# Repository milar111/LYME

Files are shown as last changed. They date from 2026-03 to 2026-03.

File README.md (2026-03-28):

# Проект LYME: Оптичен пренос на Composite Video чрез Лазер

**Екип:** EPSON  
**Състав:** Даниел Йорданов, Радослав Славов, Виктор Христов (11 "б" клас)  



---

## Съдържание
- [1. Въведение: Целта и Еволюцията на Идеята](#1-въведение-целта-и-еволюцията-на-идеята)
  - [1.1. Основна цел на проекта](#11-основна-цел-на-проекта)
  - [1.2. Ограничения и първоначални концепции](#12-ограничения-и-първоначални-концепции)
  - [1.3. Финалното решение: Аналогово видео (Composite Video / CVBS)](#13-финалното-решение-аналогово-видео-composite-video--cvbs)
  - [1.4. Архитектура на системата (The Signal Pipeline)](#14-архитектура-на-системата-the-signal-pipeline)
- [2. Източникът на видео (The Video Source & Workarounds)](#2-източникът-на-видео-the-video-source--workarounds)
  - [2.1. Проблемът с видео източника](#21-проблемът-с-видео-източника)
  - [2.2. Първоначален Proof of Concept (ESP32)](#22-първоначален-proof-of-concept-esp32)
  - [2.3. The Workaround: Raspberry Pi като Хардуерен DAC](#23-the-workaround-raspberry-pi-като-хардуерен-dac)
  - [2.4. Софтуерна конфигурация](#24-софтуерна-конфигурация)
- [3. Предавателят (Transmitter / TX) - Анатомия на сигнала](#3-предавателят-transmitter--tx---анатомия-на-сигнала)
  - [3.1. The First Principle: Защо не свържем лазера директно към видео изхода?](#31-the-first-principle-защо-не-свържем-лазера-директно-към-видео-изхода)
  - [3.2. Етап 1: DC Biasing (Преднапрежение)](#32-етап-1-dc-biasing-преднапрежение)
  - [3.3. Етап 2: AC Coupling и "The Magic Node"](#33-етап-2-ac-coupling-и-the-magic-node)
  - [3.4. Етап 3: The Driver (Emitter Follower)](#34-етап-3-the-driver-emitter-follower)
- [4. Приемникът (Receiver / RX) - Улавяне на фотоните и възстановяване на сигнала](#4-приемникът-receiver--rx---улавяне-на-фотоните-и-възстановяване-на-сигнала)
  - [4.1. Избор на сензор: Photodiode vs. Solar Panel](#41-избор-на-сензор-photodiode-vs-solar-panel)
  - [4.2. Конфигурация на сензора: Обратно преднапрежение (Reverse Bias)](#42-конфигурация-на-сензора-обратно-преднапрежение-reverse-bias)
  - [4.3. Трансимпедансен усилвател (Transimpedance Amplifier - TIA)](#43-трансимпедансен-усилвател-transimpedance-amplifier---tia)
  - [4.4. Стабилизация и Обратна връзка (The Feedback Loop)](#44-стабилизация-и-обратна-връзка-the-feedback-loop)
- [5. Capture Phase - Войната с Импеданса (Impedance Matching)](#5-capture-phase---войната-с-импеданса-impedance-matching)
  - [5.1. Проблемът с EasyCap USB Capture Card](#51-проблемът-с-easycap-usb-capture-card)
  - [5.2. Хардуерен Hack: The 75-Ohm Series Terminator](#52-хардуерен-hack-the-75-ohm-series-terminator)
  - [5.3. Sync Slicing и Фина Калибрация](#53-sync-slicing-и-фина-калибрация)
- [6. Софтуерна Част: AI Охранителна Камера](#6-софтуерна-част-ai-охранителна-камера)
  - [6.1. Обзор на системата](#61-обзор-на-системата)
  - [6.2. Архитектура и Модули](#62-архитектура-и-модули)
  - [6.3. MediaPipe: Детекция в реално време](#63-mediapipe-детекция-в-реално-време)
  - [6.4. Qwen2.5-VL: Контекстно AI разпознаване на обекти](#64-qwen25-vl-контекстно-ai-разпознаване-на-обекти)
  - [6.5. Забранена зона и Intrusion Guard](#65-забранена-зона-и-intrusion-guard)
  - [6.6. Push известия (ntfy.sh)](#66-push-известия-ntfysh)
  - [6.7. Web UI](#67-web-ui)
  - [6.8. Главен цикъл и модел на нишките (Threading Model)](#68-главен-цикъл-и-модел-на-нишките-threading-model)
  - [6.9. Flask REST API — Пълна спецификация](#69-flask-rest-api--пълна-спецификация)
  - [6.10. HUD Рендиране (Heads-Up Display)](#610-hud-рендиране-heads-up-display)
  - [6.11. Персистентност на данните](#611-персистентност-на-данните)
  - [6.12. AI Pipeline — Вътрешен поток](#612-ai-pipeline--вътрешен-поток)
  - [6.13. Зависимости и технологичен стек](#613-зависимости-и-технологичен-стек)
- [7. Инсталация и Стартиране](#7-инсталация-и-стартиране)
  - [7.1. Локална инсталация (без Docker)](#71-локална-инсталация-без-docker)
  - [7.2. Docker контейнеризация](#72-docker-контейнеризация)
  - [7.3. Конфигурация](#73-конфигурация)
  - [7.4. Тестване на Docker контейнеризацията](#74-тестване-на-docker-контейнеризацията)

---

## 1. Въведение: Целта и Еволюцията на Идеята 

### 1.1. Основна цел на проекта
Основната цел на проект LYME е изграждането на изцяло custom хардуерен оптичен линк (по въздуха, чрез лазерен лъч), способен да предава видео сигнал в реално време. 

Идеята е да се създаде стабилна система за оптична комуникация в свободно пространство (Free Space Optics), която доказва, че базов аналогов хардуер може да поддържа висока честотна лента (Bandwidth). Възможността този възстановен видео сигнал впоследствие да се подаде към лаптоп за анализ от AI модел за компютърно зрение е просто допълнително приложение (use-case). 

### 1.2. Ограничения и първоначални концепции
За да докажем концепцията (Proof of Concept) по възможно най-категоричния начин, умишлено търсихме най-трудното за реализация решение. Тривиалните методи за пренос на данни бяха изключени на ранен етап:
* **Пренос на текст (UART през оптика):** Изисква много ниска честотна лента (baud rates от порядъка на 9600 до 115200 bps). Това прави хардуерната реализация елементарна, но не демонстрира капацитета на линка.
* **Пренос на аудио:** Аудио сигналите са ограничени в тесен честотен диапазон (20Hz - 40kHz). Модулацията на лазер с аудио е възможна с базови компоненти, но отново не натоварва системата достатъчно.

Решихме да предаваме видео, защото то поставя хардуера на абсолютния му лимит. В процеса на проектиране преминахме през два неуспешни теоретични модела:

#### Провалена идея 1: Дигитално видео (Digital Baseband Transmission)
Логичният първи подход беше предаване на сурови дигитални данни (нули и единици). Проблемът тук е лимитацията на физическия слой (Physical Layer) и чистата математика на дигиталното видео:
* За да се предаде некомпресирано изображение с базова резолюция от 640x480 пиксела в 8-bit grayscale (черно-бяло), обемът данни за един единствен кадър е `640 * 480 * 1 byte = 307,200 bytes` (около 2.45 Megabits).
* Ако нашият DIY линк (базов микроконтролер и транзистор) успее да постигне скорост на превключване от 1 Mbps (което е силно оптимистично без специализирани оптични трансивъри), системата ще предава **под 0.5 кадъра в секунда (FPS)**.
* Ако целим гладко видео с минимум 15 FPS, математиката ни принуждава да намалим резолюцията до приблизително 32x32 пиксела – резолюция, която визуално не доказва нищо и е неизползваема за каквито и да е практически цели.

#### Провалена идея 2: Снимки чрез звук
Следващият подход беше конвертирането на статични изображения в аудио тонове, които лазерът да предава. 
* **Предимство:** Изключително надежден метод при наличие на интерференции, тъй като аудио честотите са лесни за филтриране.
* **Недостатък:** Кодирането и предаването на една статична снимка с приемливо качество отнема между 8 и 120 секунди. Това въвежда огромно времезакъснение (latency) и премахва елемента на "реално време".



### 1.3. Финалното решение: Аналогово видео (Composite Video / CVBS)
Решението на проблема с честотната лента се оказа връщането към аналоговите стандарти. Composite Video (CVBS) предоставя перфектния баланс между качество, скорост и хардуерна приложимост:
* Един единствен аналогов сигнал (вълна) с честотна лента от около **5 MHz** побира в себе си цялата необходима информация: синхронизиращи импулси (H-Sync/V-Sync), информация за яркостта (Luma) и цвета (Chroma).
* Вместо да се превключват милиони отделни битове (On/Off), лазерът се модулира амплитудно – неговият интензитет (яркост) следва точно напрежението на аналоговата вълна.
* Този метод заобикаля дигиталните ограничения за честотна лента и позволява постигането на плавни **50/60 кадъра в секунда (FPS)** при запазване на висока визуална разделителна способност.



### 1.4. Архитектура на системата (The Signal Pipeline)
За реализирането на тази концепция беше изграден следният комуникационен канал:

1.  **Източник:** Камера, чийто дигитален сигнал се чете от Raspberry Pi.
2.  **DAC Конвертиране:** Raspberry Pi използва хардуерния си TV-out, за да енкодира сигнала в аналогов Composite Video формат.
3.  **Transmitter (TX Circuit):** Предавателна схема, която наслагва AC видео сигнала върху DC bias и управлява мощността на лазерния диод.
4.  **Преносна среда:** Лазерен лъч в свободно пространство.
5.  **Сензор:** BPW34 фотодиод, работещ в Reverse Bias за максимална скорост.
6.  **Receiver (RX Circuit):** Transimpedance Amplifier (TIA), който конвертира микроскопичния фототок обратно във видео напрежение (Volts).
7.  **Дигитализиране:** USB Capture Card, която подава възстановения сигнал към лаптоп за визуализация и евентуален AI анализ.



## 2. Източникът на видео (The Video Source & Workarounds)

### 2.1. Проблемът с видео източника
Оптималният източник за тестване на аналогов линк е native аналогова охранителна камера (CCTV). Поради липса на такъв хардуер, се наложи да изградим система, която да генерира и излъчва валиден Composite Video (CVBS) сигнал, използвайки наличната дигитална техника.

### 2.2. Първоначален Proof of Concept (ESP32)
Преди да започнем пренос на живо видео, трябваше да изолираме променливите и да докажем, че самият аналогов лазерен линк работи. За целта използвахме **ESP32 микроконтролер**. 
* **Защо ESP32?** ESP32 разполага с хардуерни 8-битови цифрово-аналогови преобразуватели (DAC). 
* Чрез специализиран код, ESP32 генерира перфектни NTSC статични тестови екрани (Test Patterns), извеждайки аналоговата вълна директно през **Pin 26**. 
* Това позволи калибрирането на предавателя и приемника в контролирана среда, преди да въведем сложността на "живата" камера и операционната система на Raspberry Pi.

  

### 2.3. The Workaround: Raspberry Pi като Хардуерен DAC
За преноса на видео в реално време използвахме **Raspberry Pi**, свързано с дигитална камера. Raspberry Pi действа като мост и дигитално-аналогов преобразувател:
1.  Чете дигиталния видео стрийм от камерата.
2.  Използва вградения си хардуерен видео енкодер (Hardware TV-out), за да модулира дигиталните пиксели в стандартизиран аналогов PAL/NTSC CVBS сигнал.
3.  Извежда сигнала през аналоговия (жълт) RCA порт.

### 2.4. Софтуерна конфигурация
* **Операционна система (Debian Buster):** За проекта използвахме по-старата версия на Raspberry Pi OS (Buster/Legacy). Причината е чисто архитектурна: по-новите версии (Bullseye/Bookworm) използват различен графичен стек (Wayland/Mutter), който често създава конфликти при опит за директен достъп до хардуерния композитен изход. Старият стек е доказано по-стабилен за генериране на чист аналогов сигнал.
* **Headless управление (SSH):** Цялото управление се извършва безжично през SSH (`ssh pi@raspberrypi.local`). Това е критично, защото свързването на HDMI монитор за управление би изключило автоматично аналоговия композитен порт.
* **Екзекуция на потока:** Видеото се стартира чрез директна команда към видео ядрото: `sudo ffmpeg -f v4l2 -video_size 640x480 -i /dev/video0 -pix_fmt rgb565le -f fbdev /dev/fb0`

---

## 3. Предавателят (Transmitter / TX) - Анатомия на сигнала

### 3.1. The First Principle: Защо не свържем лазера директно към видео изхода?
Видео изходът на Raspberry Pi (и на повечето устройства) е стандартизиран AC (променливотоков) сигнал с амплитуда около **1.0V (peak-to-peak)**. 
От друга страна, стандартен червен лазерен диод изисква:
1.  **Постоянно напрежение (DC Bias):** Минимум 2.5V - 3.0V само за да преодолее вътрешната си бариера (Forward Voltage - $V_f$) и да започне да свети.
2.  **Ток (Current):** Около 20mA до 30mA за стабилна работа, което надвишава безопасния лимит на видео изходите.
Ако свържем лазера директно, той никога няма да светне, защото напрежението от 1V е недостатъчно. Необходимо е да изградим активна схема за смесване и усилване.

### 3.2. Етап 1: DC Biasing (Преднапрежение)
За да може лазерът да предава промените във видеото (светло/тъмно), той трябва първоначално да свети със средна интензивност. Това е "носещата" светлина.
* Използваме **10k потенциометър** свързан между +5V и GND като делител на напрежение.
* Средният пин на потенциометъра подава постоянно DC напрежение (настроено чрез въртене) през предпазен **1k резистор** към базата на транзистора. Това поддържа лазера постоянно включен в оптималната му работна точка (Q-point).

### 3.3. Етап 2: AC Coupling и "The Magic Node"
Трябва да добавим променливия видео сигнал (AC) върху постоянното захранване (DC), без двете вериги да окъсят една друга.
* Видео сигналът преминава през комбинация от паралелно свързани кондензатори: **47µF електролитен** и **100nF керамичен**.
* **Защо два кондензатора?** Електролитният кондензатор (47µF) пропуска перфектно ниските честоти (като 50Hz V-Sync импулси), но има висока паразитна индуктивност (ESL) и блокира високите честоти. Керамичният (100nF) реагира мигновено на високите честоти (MHz детайлите на картината). Работейки заедно, те покриват целия спектър на Composite Video сигнала.
* Кондензаторите блокират DC тока, но пропускат AC вълната. Точно след тях, видео вълната се наслагва върху DC напрежението от потенциометъра. Този възел ("Magic Node") съдържа перфектно миксирания сигнал, готов за усилване.

### 3.4. Етап 3: The Driver (Emitter Follower)
Слабият смесен сигнал (от порядъка на микроампери) влиза в Базата (Base) на **2N2222 NPN транзистор**.
* Транзисторът е свързан в конфигурация **Общ Колектор (Common Collector)**, известна още като **Emitter Follower**.
* **Защо тази конфигурация?** При нея транзисторът не усилва напрежението (напрежението на Емитера просто следва това на Базата, минус ~0.7V вътрешен пад), но усилва драстично **тока**. Транзисторът взема нужния голям ток директно от +5V захранването (Колектора) и го подава към лазера (Емитера), следвайки перфектно формата на видео вълната, без да натоварва Raspberry Pi-то.




## 4. Приемникът (Receiver / RX) - Улавяне на фотоните и възстановяване на сигнала

След като видео сигналът е пренесен през свободното пространство под формата на модулирана светлина, приемната страна трябва да извърши обратния процес: преобразуване на вариациите в светлинния интензитет обратно в електрическо напрежение с честотна лента от ~5 MHz.

### 4.1. Избор на сензор: Photodiode vs. Solar Panel
Често срещана грешка в любителските оптични линкове е използването на малки соларни панели като приемници. За пренос на видео този подход е физически невъзможен поради архитектурата на компонентите:
* **Соларните панели** са проектирани за енергиен добив. Те имат огромна площ на PN прехода, което води до екстремно висок вътрешен паразитен капацитет (често в порядъка на микрофаради). Този капацитет действа като нискочестотен филтър (Low-Pass Filter), ограничавайки скоростта на реакция до десетки херца.
* **PIN Фотодиодът (BPW34)**, избран за този проект, е проектиран специфично за високоскоростно предаване на данни. Той има малък капацитет и изключително бързо време за реакция (Rise/Fall time).

### 4.2. Конфигурация на сензора: Обратно преднапрежение (Reverse Bias)
Дори и бърз фотодиод като BPW34 не би се справил с 5 MHz видео сигнал, ако бъде свързан във фотоволтаичен режим (генерация на ток без външно напрежение). 
* За да постигнем необходимата скорост, BPW34 е свързан в режим на **Обратно преднапрежение (Reverse Bias)**. Анодът е свързан към отрицателната захранваща линия (**-9V**), а катодът към виртуалната нула на усилвателя.

### 4.3. Трансимпедансен усилвател (Transimpedance Amplifier - TIA)
Фотодиодът генерира ток, който е правопропорционален на падащата светлина (фототок), но този ток е микроскопичен (в порядъка на наноампери до микроампери). Стандартните видео входове изискват напрежение (обикновено около 1Vpp). За преобразуването се използва **Transimpedance Amplifier (TIA)**.

* **Избор на Операционен Усилвател (Op-Amp):** Използван е високоскоростният операционен усилвател **LM318N**. Стандартни аудио усилватели (като LM358 или TL072) са напълно неподходящи, тъй като техният Gain-Bandwidth Product (GBWP) и Slew Rate (скорост на нарастване на напрежението) са твърде ниски и биха "смачкали" видео сигнала. LM318N предлага 15 MHz честотна лента, което е повече от достатъчно за запазване на острите ръбове на синхронизиращите импулси.
* **Двойно захранване (Dual Power Supply):** Схемата се захранва с две 9V батерии, формиращи истинско двойно захранване (**+9V, GND, -9V**). Това е критично, за да може AC видео сигналът на изхода да осцилира свободно и симетрично около нулата, без да се получи изрязване (clipping) на амплитудата.

### 4.4. Стабилизация и Обратна връзка (The Feedback Loop)
Поведението на TIA се определя от компонентите в неговата обратна връзка (между изхода Pin 6 и инвертиращия вход Pin 2):
1.  **Съпротивление за усилване ($R_f = 2.2k\Omega$):** Определя коефициента на преобразуване ток-напрежение ($V_{out} = -I_{photo} \times R_f$). Стойността от 2.2k е избрана като компромис между достатъчно силен изходен сигнал и запазване на висока честотна лента.
2.  **Компенсиращ кондензатор ($C_f = 8.2pF$):** Това е най-критичният пасивен елемент в приемника. Входният капацитет на Op-Amp-а и капацитетът на фотодиода създават полюс в предавателната функция, който причинява дестабилизация и високочестотни осцилации (звънене/ringing). Паралелният кондензатор от 8.2pF е прецизно подбран (въз основа на капацитета на прехода на BPW34 при -9V), за да въведе нула в предавателната функция, която компенсира полюса. Това стабилизира усилвателя (Phase Margin > 45°) и изчиства видео сигнала.




## 5. Capture Phase - Войната с Импеданса (Impedance Matching)

След успешното възстановяване на сигнала от трансимпедансния усилвател, той трябва да бъде подаден към дигитализиращо устройство. По време на тестовете се сблъскахме със сериозен проблем на физическо ниво при прехода от аналогов към цифров формат.

### 5.1. Проблемът с EasyCap USB Capture Card
При първоначалните тестове, изходът от приемника беше подаден директно към съвременен телевизор с native RCA вход. Картината беше стабилна и ясна. Когато същият сигнал беше подаден към евтина USB Capture карта (EasyCap), изображението страдаше от тежко хоризонтално размазване (smearing/ghosting) и диагонално накъсване (Horizontal Sync Loss).

* **Причината:** Телевизорите разполагат с висококачествени схеми за автоматичен контрол на усилването (Auto Gain Control - AGC) и толерантни филтри. EasyCap устройствата използват базови и изключително стриктни "Sync Slicer" интегрирани схеми. Те очакват перфектно съгласуван сигнал с точна амплитуда от ~1.0V (peak-to-peak) и перфектни черни нива за синхронизиращите импулси.

### 5.2. Хардуерен Hack: The 75-Ohm Series Terminator
Най-критичната модификация в приемната част беше добавянето на съгласуващ резистор.
* **Физиката на проблема:** Операционният усилвател (LM318N) има много нисък изходен импеданс (близък до 0 ома) и "блъска" видео сигнала в RCA кабела с голяма мощност. Когато този сигнал стигне до Capture картата, част от енергията преминава, но друга част се отразява обратно по кабела поради несъответствие във съпротивление. Тези отражения (електрическо ехо) се наслагват върху оригиналния сигнал и причиняват визуалното хоризонтално размазване.
* **Решението:** Добавяне на **75-омов резистор последователно (в серия)** на изхода, веднага след 100µF AC Coupling кондензатора и преди централния пин на RCA жака.
* **Резултатът:** Този резистор осъществява съгласуване на импеданса на източника (Source Impedance Matching). Той абсорбира отразените от Capture картата вълни, спира "ехото" и възстановява острите вертикални ръбове на текста и обектите в картината.

### 5.3. Sync Slicing и Фина Калибрация
Диагоналното накъсване на картината се дължеше на прекалено високо напрежение на възстановения сигнал, което "заслепяваше" Sync Slicer-а на Capture картата. 
* За да може EasyCap да "заключи" картината, той трябва да разпознае H-Sync импулсите като най-ниското ниво на напрежение в целия сигнал.
* **Процесът на калибрация:** Чрез микроскопично въртене на 10k потенциометъра на **предавателя (TX)**, ние ръчно намалявахме базовия DC Bias на лазера. Това физически понижи общата амплитуда на възстановения сигнал на приемника, докато той не влезе в стриктния "прозорец" на EasyCap чипа. В този момент диагоналното разкъсване изчезна и се установи стабилен 50/60 FPS видео поток.

---

## 6. Софтуерна Част: AI Охранителна Камера

### 6.1. Обзор на системата
Софтуерната част на LYME представлява AI-базирана охранителна система, която обработва видео потока, получен от лазерния оптичен линк. Системата работи в реално време и изпълнява следните функции:

* **Детекция на хора** — чрез MediaPipe Pose Landmarker, системата разпознава човешки фигури с ниска латентност.
* **Разпознаване на обекти** — MediaPipe EfficientDet идентифицира познати обекти (чаши, бутилки, чадъри и др.) в кадъра.
* **Разпознаване на жестове** — MediaPipe Gesture Recognizer следи ръцете и разпознава жестове в реално време.
* **Контекстно AI разпознаване** — Qwen2.5-VL визуален езиков модел (VLM) анализира зоната на интерес и отговаря на въпроси от вида "Има ли бутилка в кадъра?", връщайки резултат с процент увереност.
* **Забранена зона** — потребителят дефинира полигонална зона през уеб интерфейса; навлизането на човек предизвиква аларма.
* **Push известия** — при засечени нарушения или обекти, системата автоматично изпраща push нотификации през ntfy.sh към телефон/компютър.

### 6.2. Архитектура и Модули

```
main.py                     ← Входна точка: стартира камера, AI, Flask сървър
├── src/
│   ├── tracker.py           ← VisionTracker: обвива 3-те MediaPipe модела
│   ├── actions.py           ← Зарежда Qwen2.5-VL и изпълнява AI заявки
│   ├── context_manager.py   ← Списък с наблюдавани обекти + генерира промпти
│   ├── zone_manager.py      ← Логика за забранена зона (полигон)
│   ├── intrusion_guard.py   ← State machine: CLEAR → DWELLING → INTRUDING
│   ├── alerts.py            ← Логване на събития + запис на snapshot-и
│   ├── notifier.py          ← Push известия чрез ntfy.sh
│   └── config.py            ← Централна конфигурация
├── demo_app/
│   └── templates/
│       └── index.html       ← Web UI (единичен HTML файл)
├── Dockerfile               ← Docker image дефиниция
├── docker-compose.yml       ← Оркестрация
└── requirements.txt         ← Python зависимости
```

### 6.3. MediaPipe: Детекция в реално време
Модулът `VisionTracker` (`src/tracker.py`) инициализира три MediaPipe модела, които работят паралелно в **LIVE_STREAM** режим:

| Модел | Файл | Функция |
|---|---|---|
| Pose Landmarker Full | `pose_landmarker_full.task` | Детекция на 33 точки от тялото на човек |
| EfficientDet Lite0 | `efficientdet_lite0.tflite` | Обща детекция на обекти (COCO dataset) |
| Gesture Recognizer | `gesture_recognizer.task` | Разпознаване на жестове на ръце |

Моделите се изтеглят автоматично от Google Storage при първо стартиране. Резултатите от всеки модел се записват чрез callback функции, което позволява неблокиращо (асинхронно) обработване на кадри.

**Pose Landmarker** е ключов за функцията "Забранена зона" — центърът на тялото (средна точка между лявото и дясното рамо) се изчислява и проверява дали попада в дефинирания полигон.

### 6.4. Qwen2.5-VL: Контекстно AI разпознаване на обекти
За задачи, които MediaPipe не може да покрие (например "Има ли бутилка вода в зоната?"), системата използва **Qwen2.5-VL-3B-Instruct** — 3-милиарден параметър визуален езиков модел (VLM), работещ изцяло локално на CPU.

**Как работи:**
1. Потребителят добавя обект за наблюдение (напр. "bottle") през уеб интерфейса.
2. Системата генерира детайлен промпт: *"Look very carefully at this image. Is there a 'bottle' (or any similar/related object) visible anywhere in the frame, even partially, at an angle, in shadow, or partially outside the frame?..."*
3. На всеки 5 секунди (`_AI_INTERVAL`), Qwen получава текущия кадър (изрязан до забранената зона) и един от промптите. Обработката се случва в отделна нишка, за да не блокира видео потока.
4. Моделът отговаря в строго дефиниран формат: `CONFIDENCE: 85% | yes | A water bottle is visible on the table`
5. Отговорът се парсва за **процент увереност** и **да/не** решение.

**Система за потвърждение (Dwell):** За да се избегнат фалшиви аларми, обектът трябва да бъде засечен **поне 2 пъти последователно** (в рамките на `_ITEM_DWELL_SECONDS = 2.0s`), преди да се изпрати push известие. При всяко сканиране, процентът увереност се визуализира в реално време както в уеб интерфейса, така и директно върху видео потока.

### 6.5. Забранена зона и Intrusion Guard
Системата за забранена зона се състои от два комплементарни модула:

**Zone Manager** (`src/zone_manager.py`):
* Зоната е полигон, дефиниран с нормализирани координати (0.0–1.0) и съхранен в `data/zone.json`.
* Потребителят рисува полигона директно върху видео потока чрез уеб интерфейса — кликване добавя точка, десен клик премахва последната, бутон "Confirm" записва зоната.
* Функцията `body_centre_in_zone()` използва `cv2.pointPolygonTest()` за проверка дали центърът на тялото попада вътре в полигона.

**Intrusion Guard** (`src/intrusion_guard.py`):
* Реализира State Machine с три състояния:
  - **CLEAR** — Няма човек в зоната.
  - **DWELLING** — Човек е засечен, но тече период на изчакване (`INTRUSION_DWELL_SECONDS = 2.0s`), визуализиран с progress bar на екрана.
  - **INTRUDING** — Потвърдено нарушение. Активира се аларма, записва се snapshot, изпраща се push известие.
* Този подход с "dwell time" елиминира фалшиви аларми от моментно преминаване или грешки в детекцията.

### 6.6. Push известия (ntfy.sh)
Модулът `src/notifier.py` изпраща push известия чрез безплатния и open-source сервис **ntfy.sh**. Не се изисква регистрация — достатъчно е да се абонирате за topic-а (конфигуриран в `src/config.py` → `NTFY_TOPIC`).

**Типове известия:**
| Събитие | Приоритет | Описание |
|---|---|---|
| 🚨 INTRUSION DETECTED | urgent | Човек навлязъл в забранената зона |
| ✅ Zone cleared | default | Зоната е отново празна |
| 🔍 OBJECT DETECTED | urgent | AI моделът е засякъл наблюдаван обект |

Всяко известие включва AI описание и процент увереност. Intrusion alert-ите съдържат допълнителен контекст за всички текущо наблюдавани обекти.

### 6.7. Web UI
Интерфейсът (`demo_app/templates/index.html`) е единичен HTML файл, сервиран от Flask на порт **4000**. Той предоставя:

* **Видео стрийм** — MJPEG поток (`/video_feed`) с наложени HUD елементи (confidence overlay, intrusion banner, dwell progress bar).
* **Панел "System Status"** — Текущо състояние: CLEAR / DWELLING / INTRUDING.
* **Панел "Forbidden Zone"** — Рисуване, потвърждаване и изчистване на полигонална зона.
* **Панел "Monitor For"** — Добавяне/премахване на обекти за AI наблюдение (напр. bottle, knife, bag).
* **Панел "AI Detections"** — За всеки обект: статус иконка (⏳/⚠️/✅), процент увереност с цветен индикатор, кратко описание от AI модела, progress bar с увереност.
* **Event Log** — Хронологичен лог на всички събития.
* **Бутон "Shutdown"** — Спира системата.

### 6.8. Главен цикъл и модел на нишките (Threading Model)
Системата използва многонишков (multi-threaded) модел, за да осигури едновременна работа на видео обработката и уеб сървъра:

**Стартова последователност:**
1. `actions.init_model()` — зарежда Qwen2.5-VL модела в паметта (~6 GB RAM на CPU).
2. `VisionTracker()` — инициализира трите MediaPipe модела; при първо стартиране ги изтегля автоматично от Google Storage.
3. `cv2.VideoCapture()` — отваря камерата (индексът се конфигурира от `config.CAMERA_SOURCE`).
4. `init_zone()` / `init_context()` — зареждат запазената забранена зона и списъка с наблюдавани обекти от `data/`.
5. Flask сървърът се стартира в **daemon нишка** (`threading.Thread(target=run_flask, daemon=True)`).

**Нишки в системата:**

| Нишка | Описание |
|---|---|
| **Main Thread** | Главният цикъл `while _running` — чете кадри от камерата, обработва ги чрез MediaPipe, проверява зоната, рисува HUD-а и обновява `WebUIState`. |
| **Flask Thread** | Daemon нишка — сервира уеб интерфейса на порт 4000 и обслужва REST API заявки. |
| **Qwen AI Thread** | Порожда се при нужда (на всеки `_AI_INTERVAL = 5s`) — изпълнява `_run_qwen_async()` в отделна daemon нишка. Използва `_ai_busy` флаг за да предотврати припокриване. |
| **Notifier Thread** | Порожда се при всяко push известие — изпраща HTTP POST към ntfy.sh асинхронно. |
| **Alert Thread** | Порожда се при всяка аларма — записва snapshot и логва събитието без да блокира видео потока. |

**Синхронизация:** Споделеното състояние (`WebUIState`, `_answers`, `_questions`, `_items`) е защитено с `threading.Lock` обекти. Флагът `_ai_busy` предотвратява стартирането на втора Qwen заявка, докато предишната не е завършила.

**Грациозно спиране:** Натискането на `Ctrl+C` или извикването на `POST /shutdown` задава `_running = False`, което прекъсва главния цикъл. Блокът `finally` освобождава камерата и затваря MediaPipe моделите.

### 6.9. Flask REST API — Пълна спецификация
Flask сървърът е достъпен на `http://localhost:4000` и предоставя следните ендпойнти:

| Метод | Ендпойнт | Описание |
|---|---|---|
| `GET` | `/` | Сервира `index.html` — уеб интерфейса |
| `GET` | `/video_feed` | MJPEG стрийм — непрекъснат поток от JPEG кадри с наложен HUD |
| `GET` | `/status` | JSON: `person_in_sight`, `is_intruding`, `guard_state`, `dwell_progress`, `last_seen_ago`, `frame_count`, `object_alert` |
| `GET` | `/ai_status` | JSON масив с елементи за всеки наблюдаван обект: `item`, `answer`, `description`, `confidence`, `detected` |
| `GET` | `/zone` | JSON: текущите нормализирани точки на полигона (или `null`) |
| `POST` | `/zone` | Приема JSON `{"points": [{x, y}, ...]}` — записва зоната и я зарежда без рестарт |
| `DELETE` | `/zone` | Изтрива забранената зона от паметта и от `data/zone.json` |
| `GET` | `/context` | JSON масив с имена на наблюдавани обекти |
| `POST` | `/context` | Приема JSON `{"item": "bottle"}` — добавя нов обект за AI наблюдение |
| `DELETE` | `/context/<idx>` | Премахва обект по индекс от списъка |
| `POST` | `/shutdown` | Спира системата — задава `_running = False` |
| `GET` | `/debug/ai_crop` | Debug ендпойнт — показва изрязания кадър, който Qwen вижда |

**MJPEG потокът** (`/video_feed`) е реализиран чрез `multipart/x-mixed-replace` MIME тип. Браузърът получава непрекъснат поток от JPEG изображения, разделени с boundary маркери — не е необходим WebSocket или допълнителен JavaScript за видео визуализация.

### 6.10. HUD Рендиране (Heads-Up Display)
Всеки кадър от видео потока се обогатява с визуални елементи преди кодирането му в JPEG:

* **Зони** (`draw_zones()`): Забранената зона се рисува като полупрозрачен червен полигон (`cv2.fillPoly` + `cv2.addWeighted` с alpha = 0.25). При активна аларма, прозрачността се увеличава до 0.45 и контурът се удебелява. Текстът "FORBIDDEN ZONE" се позиционира в центъра на полигона, а "FREE ZONE" — в средната точка на свободната област.

* **AI Confidence Overlay** (`_draw_ai_confidence_hud()`): В горния ляв ъгъл се рендира полупрозрачен панел с информация за всеки наблюдаван обект:
  - `[?]` сиво — AI все още не е сканирал
  - `[OK]` зелено — обектът не е засечен (confidence < 40%)
  - `[~]` оранжево — несигурен резултат (40-59%)
  - `[!]` червено — обектът е засечен (confidence ≥ 60%)

* **Dwell Progress Bar**: Когато човек е в зоната и системата е в състояние `DWELLING`, в долната част на кадъра се рисува оранжева лента, запълваща се от 0% до 100% за `INTRUSION_DWELL_SECONDS` секунди.

* **Intrusion Banner**: При потвърдено нарушение (`INTRUDING`), в долната част се изписва мигащ червен банер "!! INTRUSION DETECTED !!" върху полупрозрачен черен фон. Рамката на целия кадър става червена.

### 6.11. Персистентност на данните
Системата съхранява данни в директория `data/`, която се създава автоматично при първо стартиране:

| Файл / Директория | Описание |
|---|---|
| `data/zone.json` | Нормализирани координати на забранената зона `[[x, y], ...]` |
| `data/context.json` | JSON масив с имена на наблюдавани обекти `["bottle", "knife"]` |
| `data/logs.txt` | Текстов лог с времеви печат за всяко събитие (intrusion, object detection) |
| `data/snapshots/` | JPEG изображения, записвани автоматично при аларма (`intrusion_YYYYMMDD_HHMMSS.jpg`) |
| `data/.model_initialized` | Флагов файл, указващ че моделите са инициализирани |

При Docker контейнеризация, `data/` директорията се монтира като volume (`./data:/app/data`), така че данните преживяват рестартиране на контейнера.

### 6.12. AI Pipeline — Вътрешен поток
AI обработката следва строго определен поток, оптимизиран за минимална интерференция с видео потока:

```
┌─────────────────────────────────────────────────────────────────────┐
│                        Главен цикъл (Main Thread)                  │
│                                                                     │
│  1. Проверка: изминали ли са >= 5s от последното AI сканиране?      │
│  2. Проверка: _ai_busy == False? (предишната заявка завършила ли е?)│
│  3. Проверка: има ли поне 1 обект за наблюдение?                   │
│  4. Проверка: зоната активна ли е?                                 │
│                                                                     │
│  Ако всичко е ✓ → порожда нова нишка с _run_qwen_async()          │
│  Обектите се сканират кръгово (round-robin): _blip_idx % len(items)│
└──────────────────────────┬──────────────────────────────────────────┘
                           │
                           ▼
┌─────────────────────────────────────────────────────────────────────┐
│                     _run_qwen_async() (AI Thread)                  │
│                                                                     │
│  1. Изрязва кадъра до bounding rect на забранената зона            │
│  2. Конвертира BGR → RGB → PIL Image                               │
│  3. Изгражда chat prompt с image + text                            │
│  4. Tokenизира чрез AutoProcessor                                   │
│  5. model.generate(max_new_tokens=64)                              │
│  6. Декодира отговора: "CONFIDENCE: 85% | yes | A bottle is here"  │
│  7. Парсва confidence % и yes/no                                    │
│  8. Записва отговора в _answers[idx] (под _ai_lock)                │
│                                                                     │
│  При "yes" + dwell >= 2s + cooldown изтекъл → push известие         │
│  При "no" → нулира dwell таймера за този обект                     │
└─────────────────────────────────────────────────────────────────────┘
```

**Round-Robin сканиране:** Ако потребителят наблюдава 3 обекта (bottle, knife, bag), системата ги сканира последователно: на 0-та секунда — bottle, на 5-та — knife, на 10-та — bag, на 15-та — отново bottle, и т.н.

**Dwell за обекти:** Подобно на Intrusion Guard, обектите също имат dwell механизъм (`_ITEM_DWELL_SECONDS = 2.0s`). AI трябва да засече обекта поне два пъти последователно, преди да изпрати push известие. Cooldown-ът между push-ове за един и същ обект е `_ITEM_PUSH_COOLDOWN = 60s`.

### 6.13. Зависимости и технологичен стек
Системата използва следните основни технологии:

| Технология | Версия | Предназначение |
|---|---|---|
| **Python** | 3.10+ | Основен език |
| **Flask** | 3.1.3 | HTTP сървър и REST API |
| **OpenCV** (`opencv-python`) | 4.9.0 | Видео захващане, обработка на изображения, HUD рендиране |
| **MediaPipe** | 0.10.21 | Pose detection, object detection, gesture recognition (LIVE_STREAM) |
| **PyTorch** | 2.2.2 | Backend за Qwen2.5-VL (CPU inference) |
| **Transformers** (Hugging Face) | 4.49.0 | Зареждане и inference на Qwen2.5-VL модела |
| **qwen-vl-utils** | 0.0.14 | Помощни функции за обработка на vision input за Qwen |
| **Pillow** | 12.1.1 | Конвертиране BGR → RGB → PIL Image за AI модела |
| **Requests** | 2.33.0 | HTTP заявки (ntfy.sh push нотификации) |
| **torchvision** | 0.17.2 | Допълнителен модул за PyTorch (зависимост на Transformers) |
| **accelerate** | 1.13.0 | Оптимизиране на зареждането на модела |
| **NumPy** | 1.26.4 | Числени операции с масиви (полигони, координати) |

**Външни сервиси:**
* **ntfy.sh** — безплатен open-source push notification сервис. Не изисква регистрация. Използва се за изпращане на аларми към телефон/браузър.
* **Google Storage** — за автоматично изтегляне на MediaPipe `.task`/`.tflite` модели при първо стартиране.
* **Hugging Face Hub** — за изтегляне на Qwen2.5-VL-3B-Instruct модела (~6 GB) при първо стартиране. Кешира се в `~/.cache/huggingface/hub/`.

---

## 7. Инсталация и Стартиране

### 7.1. Локална инсталация (без Docker)

**Изисквания:**
* Python 3.10+
* Уеб камера (вградена или USB)
* ~6 GB свободна RAM (Qwen2.5-VL-3B работи на CPU)

**Стъпки:**

```bash
# 1. Клониране на хранилището
git clone https://github.com/milar111/LYME.git
cd LYME

# 2. Създаване на виртуална среда
python3 -m venv .venv
source .venv/bin/activate

# 3. Инсталиране на зависимости
pip install -r requirements.txt

# 4. Изтегляне на Qwen2.5-VL модела (при първо стартиране, ~6 GB)
# Моделът се кешира автоматично в ~/.cache/huggingface/hub/
# MediaPipe моделите (pose, object detection, gestures) се изтеглят автоматично.

# 5. Стартиране
python main.py
```

Отворете `http://localhost:4000` в браузъра.

### 7.2. Docker контейнеризация

Docker позволява стартиране на системата без ръчна инсталация на зависимости. Камерата на хоста се пренасочва в контейнера чрез device mapping.

> **Забележка:** Docker контейнеризацията е предназначена за **Linux** и **Windows (WSL2)**. На macOS, Docker няма достъп до уеб камерата на хоста.

**Стъпки:**

```bash
# 1. Клониране
git clone https://github.com/milar111/LYME.git
cd LYME

# 2. Стартиране с docker-compose
docker compose up --build
```

Контейнерът ще:
1. Инсталира всички Python зависимости автоматично.
2. Изтегли MediaPipe моделите при първо стартиране.
3. Изтегли Qwen2.5-VL от Hugging Face (при първо стартиране, кешира се в контейнера).
4. Стартира системата на порт **4000**.

**Достъп до камерата:**
```yaml
# docker-compose.yml — Променете устройството ако камерата е на друг индекс:
devices:
  - /dev/video0:/dev/video0   # на Linux
```

За Windows с WSL2, камерата се пренасочва автоматично чрез WSL USB passthrough.

**Полезни команди:**
```bash
docker compose up -d          # Стартиране на заден план
docker compose logs -f        # Следене на логовете
docker compose down           # Спиране
docker compose up --build     # Преизграждане след промени в кода
```

### 7.3. Конфигурация
Файлът `src/config.py` съдържа основните параметри:

| Параметър | Стойност | Описание |
|---|---|---|
| `CAMERA_SOURCE` | `0` | Индекс на камерата (0 = първа камера) |
| `AI_MODEL_NAME` | `Qwen/Qwen2.5-VL-3B-Instruct` | Hugging Face идентификатор на VLM модела |
| `INTRUSION_DWELL_SECONDS` | `2.0` | Секунди изчакване преди потвърждаване на нарушение |
| `ALERT_COOLDOWN_SECONDS` | `30` | Минимален интервал между две аларми |
| `NTFY_TOPIC` | `hacktues` | ntfy.sh topic за push известия |

За получаване на известия, инсталирайте ntfy приложението ([ntfy.sh](https://ntfy.sh)) и се абонирайте за topic-а, зададен в `NTFY_TOPIC`.

### 7.4. Тестване на Docker контейнеризацията

#### Предварителни изисквания
* **Docker Engine** инсталиран и работещ (`docker --version`)
* **Docker Compose** v2+ (`docker compose version`)
* За Linux: уеб камера достъпна на `/dev/video0` (проверете с `ls -la /dev/video*`)
* За Windows: WSL2 с USB passthrough конфигуриран

#### Стъпка 1: Изграждане на образа (Build)

```bash
# Изграждане без стартиране — проверява дали Dockerfile е валиден
docker compose build

# Или директно с docker build (за по-детайлен контрол):
docker build -t lyme-camera .
```

Успешният build завършва с `Successfully built ...` и не трябва да има грешки. Очаквано време: 3–10 минути (зависи от интернет скоростта за pip install).

#### Стъпка 2: Тест без камера (Smoke Test)

Ако нямате достъп до камера (например на macOS), можете да проверите дали контейнерът стартира коректно и зарежда зависимостите:

```bash
# Стартиране в интерактивен режим без device mapping
docker run --rm -it -p 4000:4000 lyme-camera python -c "
import flask, cv2, mediapipe, torch, transformers
print('Flask:', flask.__version__)
print('OpenCV:', cv2.__version__)
print('MediaPipe:', mediapipe.__version__)
print('PyTorch:', torch.__version__)
print('Transformers:', transformers.__version__)
print()
print('All dependencies OK ✓')
"
```

#### Стъпка 3: Пълно стартиране с камера

```bash
# На Linux с камера:
docker compose up --build

# Проверете логовете за успешно стартиране:
# [main] Loading Qwen2.5-VL model...
# [main] Initialising MediaPipe tracker...
# [main] Web UI → http://localhost:4000
# [main] Running — press Ctrl+C to quit.
```

#### Стъпка 4: Проверка на здравето на контейнера (Health Check)

```bash
# Проверка дали контейнерът работи
docker ps | grep lyme

# Проверка на REST API ендпойнтите
curl -s http://localhost:4000/status | python3 -m json.tool
curl -s http://localhost:4000/zone | python3 -m json.tool
curl -s http://localhost:4000/context | python3 -m json.tool
curl -s http://localhost:4000/ai_status | python3 -m json.tool

# Проверка на видео потока (трябва да върне MJPEG данни)
curl -s --max-time 2 http://localhost:4000/video_feed | head -c 100
```

#### Стъпка 5: Тест на data volume

```bash
# Проверете дали data/ директорията се монтира правилно
docker compose up -d
# Добавете обект за наблюдение чрез API:
curl -X POST http://localhost:4000/context \
     -H "Content-Type: application/json" \
     -d '{"item": "bottle"}'

# Спрете и стартирайте отново — обектът трябва да се запази:
docker compose down
docker compose up -d
curl -s http://localhost:4000/context | python3 -m json.tool
# Очакван резултат: {"items": ["bottle"]}
```

#### Стъпка 6: Проверка на ресурсите

```bash
# Мониторинг на RAM и CPU използване
docker stats lyme_camera

# Очаквани стойности:
# - RAM: ~2-3 GB при зареждане, ~6-8 GB при AI inference
# - CPU: ~30-60% при видео обработка, ~100% при Qwen inference
```

#### Отстраняване на проблеми (Troubleshooting)

| Проблем | Решение |
|---|---|
| `Cannot open camera` | Проверете device mapping: `devices: - /dev/video0:/dev/video0` в `docker-compose.yml` |
| `ModuleNotFoundError` | Преизградете образа: `docker compose build --no-cache` |
| Контейнерът се срива (OOM) | Увеличете Docker RAM лимита (минимум 8 GB за Qwen модела) |
| Портът е зает | Променете port mapping: `"4001:4000"` в `docker-compose.yml` |
| macOS: няма камера | Docker Desktop за macOS не поддържа USB passthrough — използвайте локална инсталация (7.1) |
| Бавно първо стартиране | Нормално е — Qwen модел (~6 GB) и MediaPipe модели се изтеглят еднократно |

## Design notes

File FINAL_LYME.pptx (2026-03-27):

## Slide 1

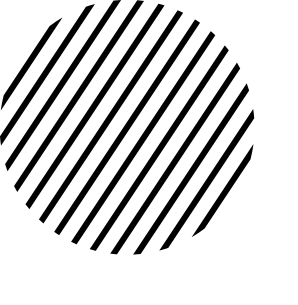
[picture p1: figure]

LYME

Представено от отбор EPSON

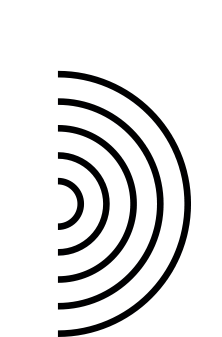
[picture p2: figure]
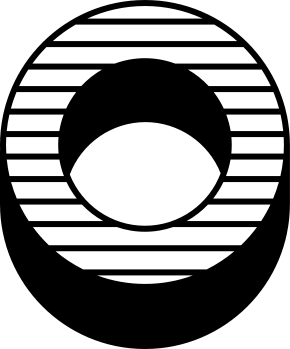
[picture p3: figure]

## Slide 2

НАШИЯТ ОТБОР - EPSON

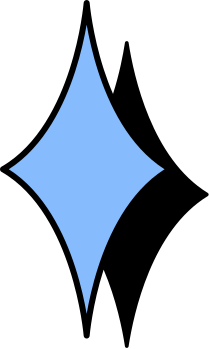
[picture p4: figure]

Даниел Йорданов

Радослав Славов

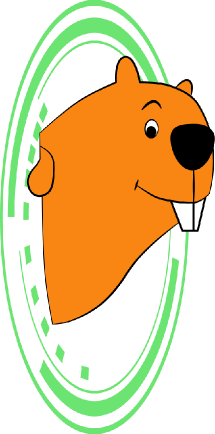
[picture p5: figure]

Виктор Христов

Филип Лесов - нашият ментор

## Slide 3

НАСТОЯЩИЯ ПРОБЛЕМ

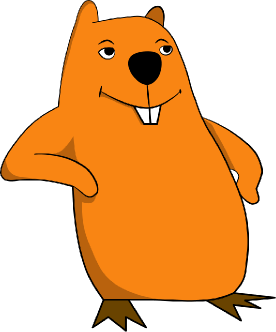
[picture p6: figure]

Заглушаване на сигнала

Нежелан Достъп до видеопотока

Неспособност да се изолира параметър за наблюдение

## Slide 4

КАКВО ПРЕДЛАГА LYME

Премахваме необходимостта от физически връзки

Предаване на сигнал, който да не бъде заглушен

Ускорена обработка на данни

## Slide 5

КАК РАБОТИ LYME

Hardware layer

Software layer

Graphic User Interface

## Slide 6

ТЕХНОЛОГИИТЕ ЗАД LYME

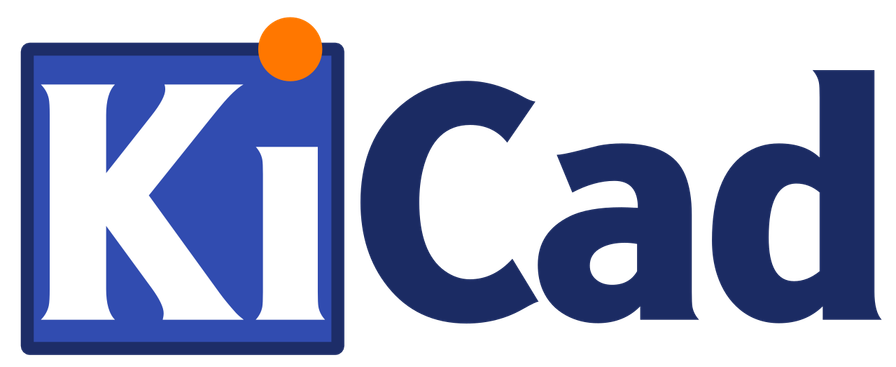
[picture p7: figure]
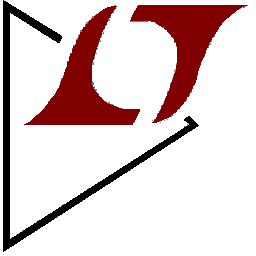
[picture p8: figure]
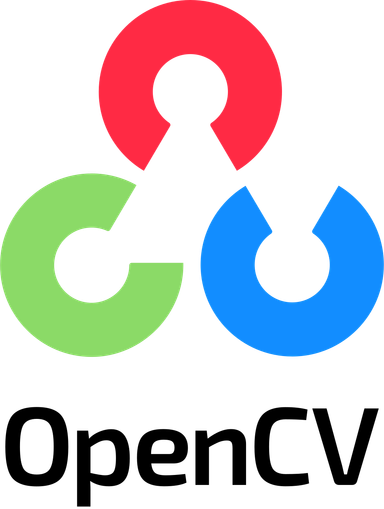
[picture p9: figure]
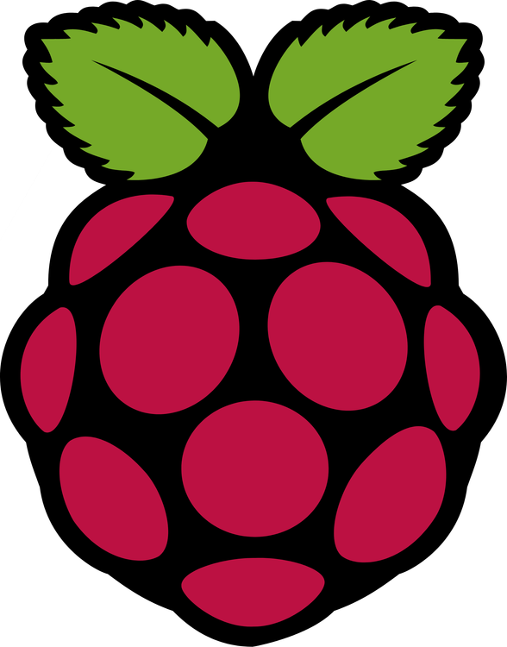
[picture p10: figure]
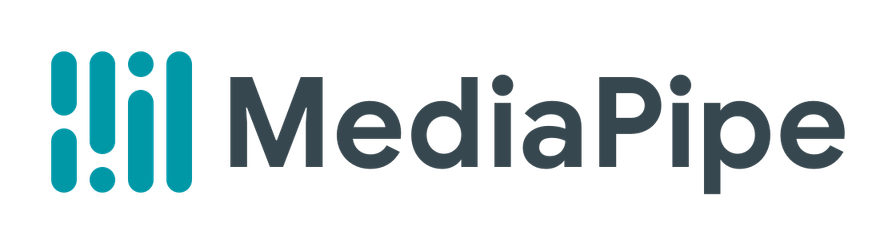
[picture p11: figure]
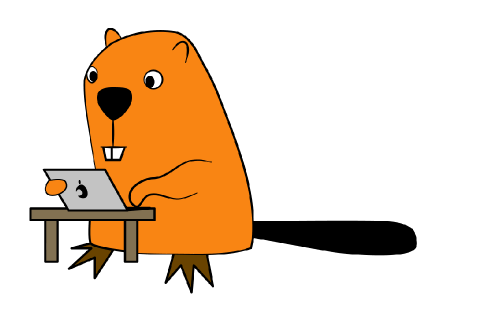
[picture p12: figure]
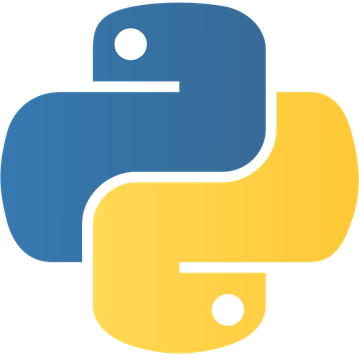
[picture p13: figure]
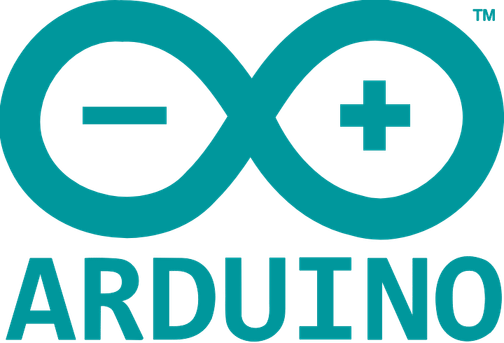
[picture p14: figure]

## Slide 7

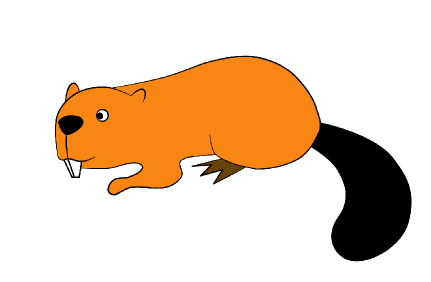
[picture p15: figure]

DEMO

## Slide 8

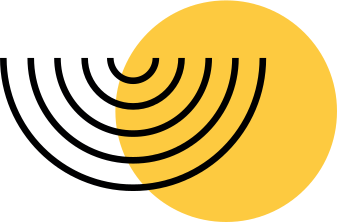
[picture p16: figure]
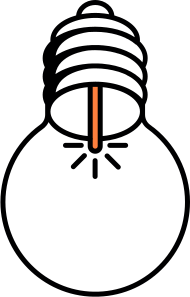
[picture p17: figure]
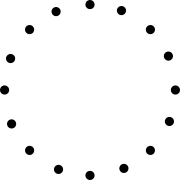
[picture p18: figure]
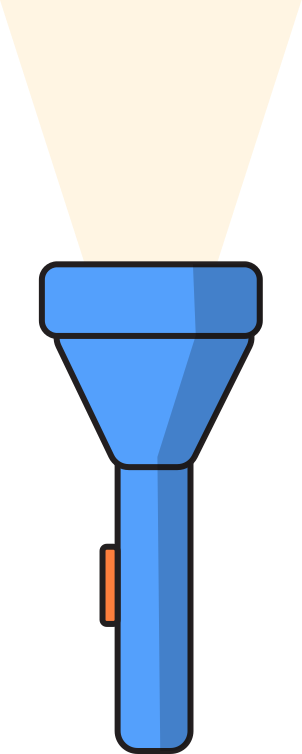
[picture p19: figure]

БЛАГОДАРИМ ВИ ЗА ВНИМАНИЕТО!

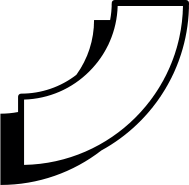
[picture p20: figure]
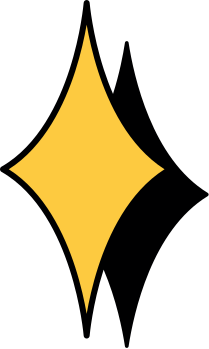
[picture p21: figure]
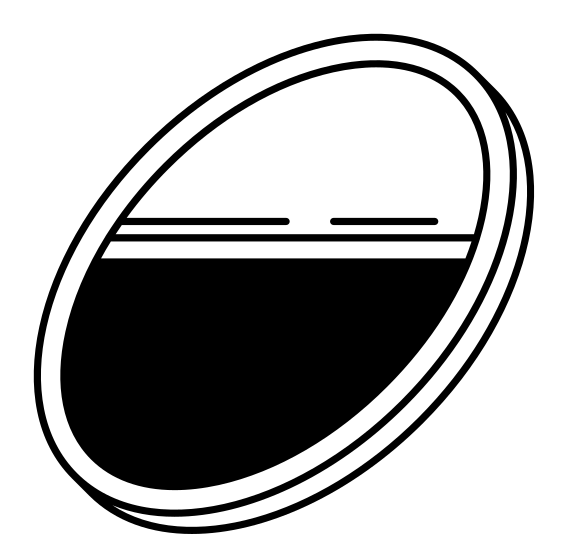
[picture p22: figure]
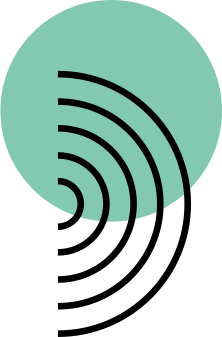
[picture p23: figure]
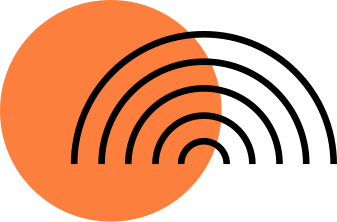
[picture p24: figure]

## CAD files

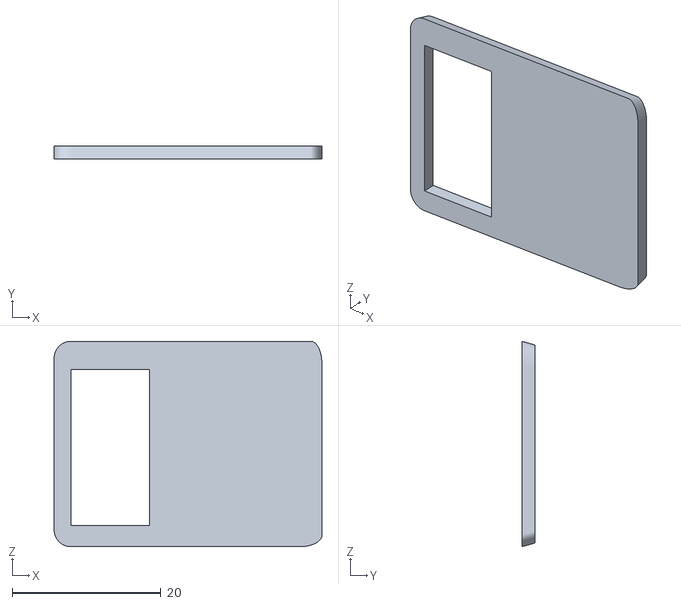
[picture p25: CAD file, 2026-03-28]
3dFiles/lidRX.stl
36.0 x 1.75 x 27.6

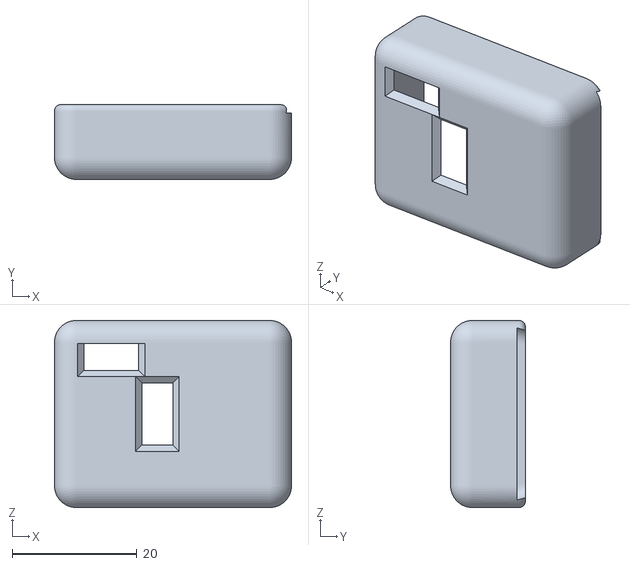
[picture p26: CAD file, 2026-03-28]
3dFiles/boxRX.stl
38.0 x 12.0 x 30.0

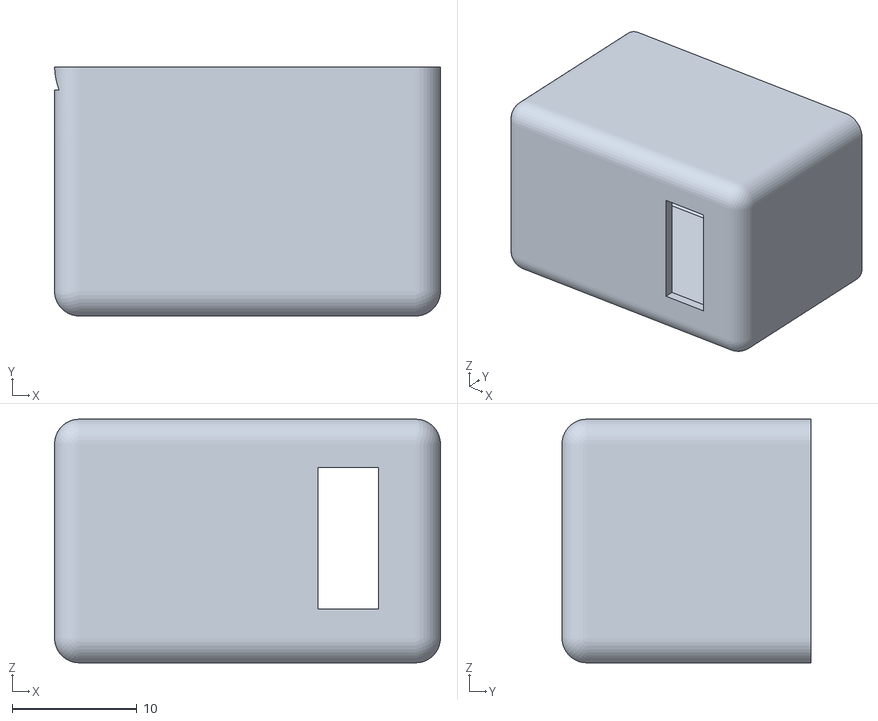
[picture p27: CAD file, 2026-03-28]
3dFiles/boxTX.stl
31.0 x 20.0 x 19.6

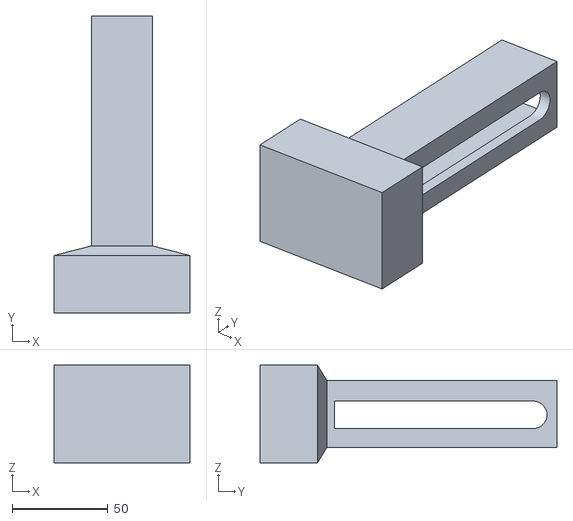
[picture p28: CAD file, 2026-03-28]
3dFiles/base.stl
71.0 x 155.0 x 51.0

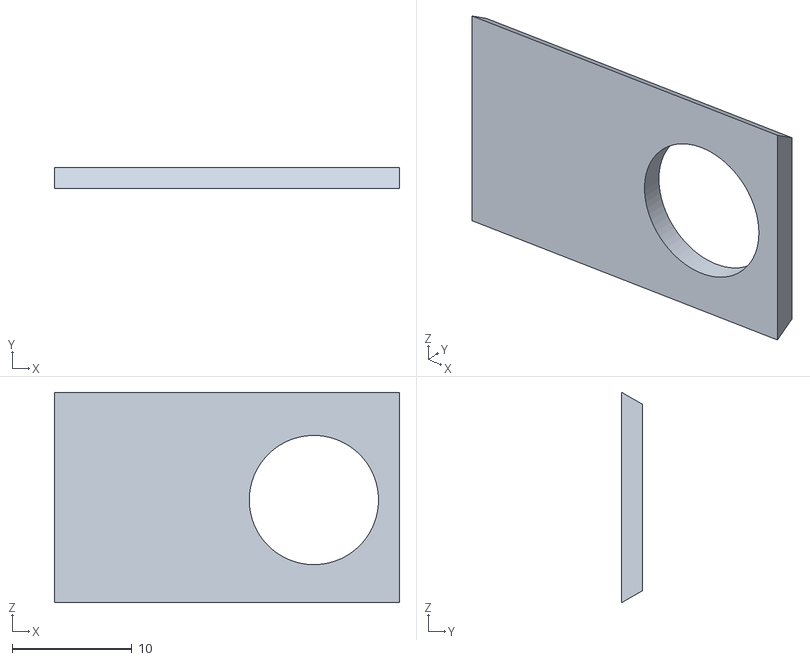
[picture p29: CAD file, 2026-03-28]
3dFiles/lidTX.stl
28.8 x 1.74 x 17.6

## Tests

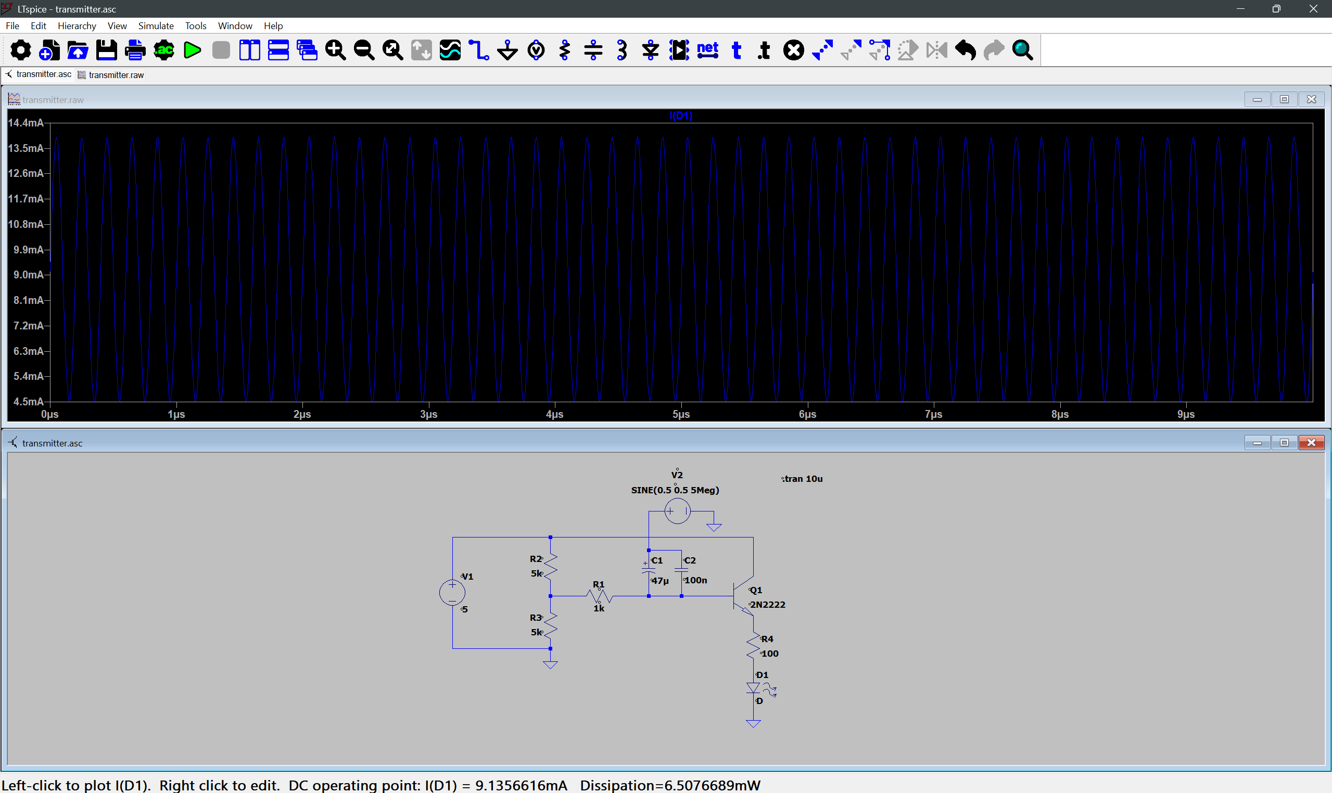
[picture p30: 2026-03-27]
simulations/sim_results/transmitter/transmitter_led_drive_current.png

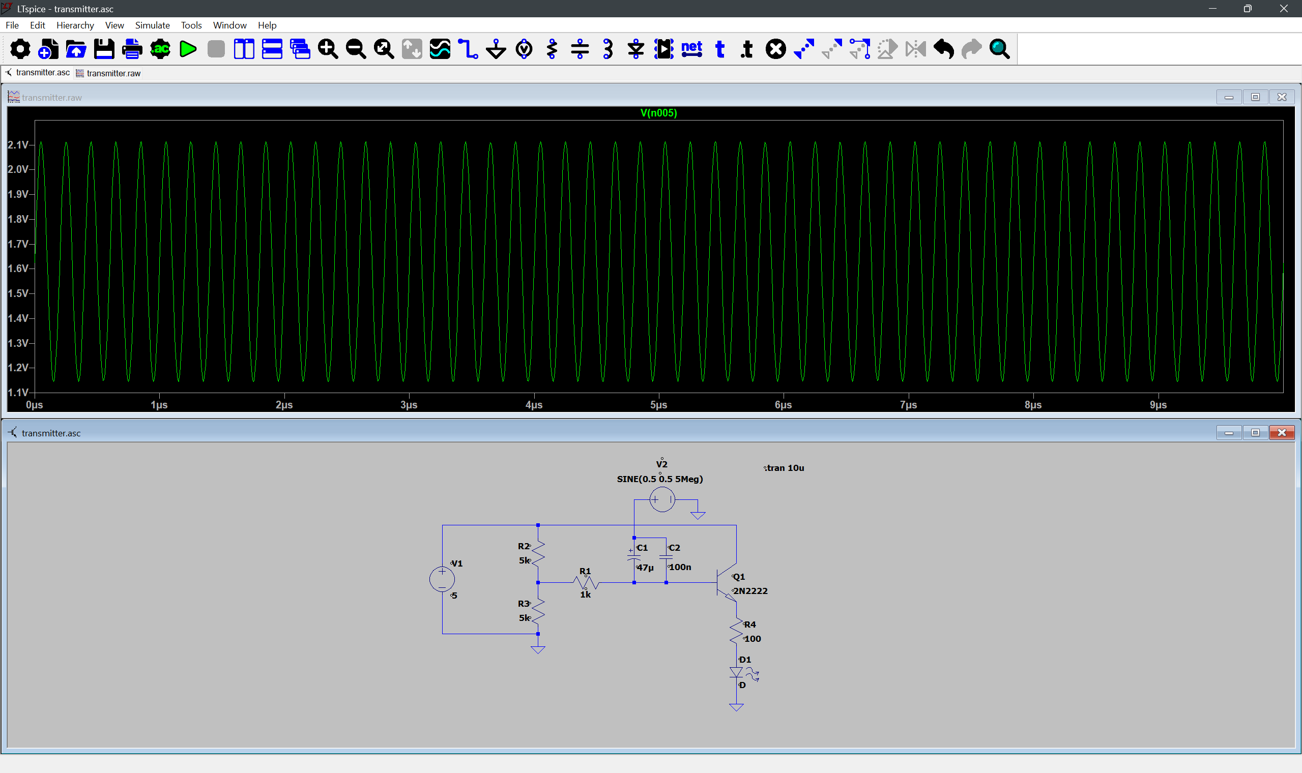
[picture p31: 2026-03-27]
simulations/sim_results/transmitter/transmitter_biased_voltage_output.png

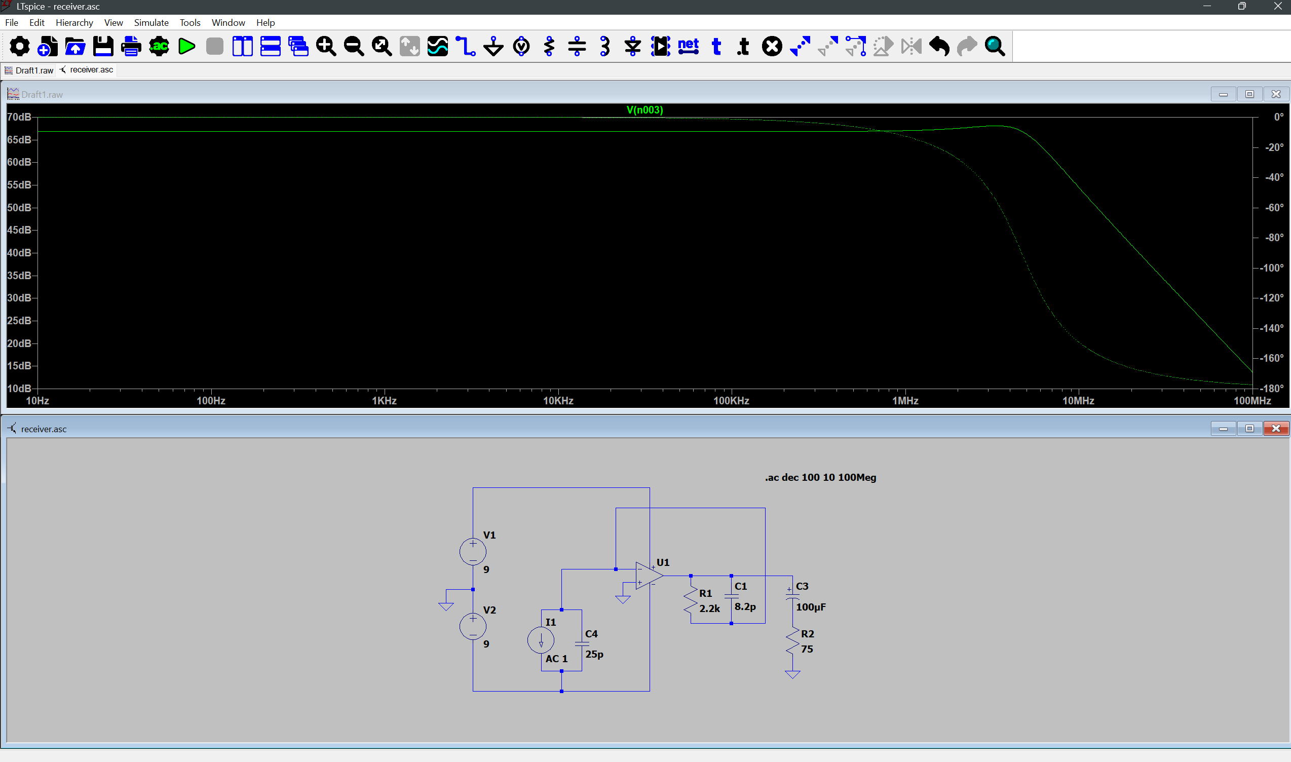
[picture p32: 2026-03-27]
simulations/sim_results/receiver/response_optimal_8.2pF.png

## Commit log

2026-03-26 Add KiCad transmitter design files
    Initial import of the 'transmitter' KiCad project.
    [transmitter.kicad_pcb, transmitter.kicad_sch]
2026-03-26 add LTspice simulation for transmitter biasing
    Validated the transmitter circuit with a 1Vpp 5MHz video signal:
    - Verified 1.6V DC bias to prevent signal clipping.
    - Confirmed LED drive current pulses safely between 4.5mA and 14.4mA. PLus min current.
    Includes:
    - transmitter.asc: LTspice schematic
    - tx_voltage_transient.png: Voltage waveform
    - tx_led_current.png: LED current waveform
2026-03-26 Initial files and brown detection at the moment just to test the camera
2026-03-26 Add KiCad receiver design files
    Receiver design in KiCad:
    - Integrated LM318N high-speed op-amp for wide-bandwidth video processing.
    - Optimized feedback loop with a 2.2k resistor and 8.2pF??? compensation capacitor.
    - Configured BPW34 photodiode in reverse-bias mode for reduced junction capacitance.
    - Added +/- 9V dual-rail power supply and decoupling capacitors (100nF) for stability.
    [receiver.kicad_pcb, receiver.kicad_sch]
2026-03-26 Check with a local live feed camera
2026-03-27 Final combined version with a new button to shutdown directly through the UI
2026-03-27 75 ohm resistor included
    [receiver.kicad_sch]
2026-03-28 3d files
    [base.stl, boxRX.stl, boxTX.stl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]
